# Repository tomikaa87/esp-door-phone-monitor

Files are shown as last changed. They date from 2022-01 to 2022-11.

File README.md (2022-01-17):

ESP Door Phone Monitor is an ESP8266-based device that monitors specific door phone types. It's able to check if the phone is ringing and also mute the ringer. The MQTT API makes it simple to integrate into various home automation systems, like Homebridge.

# Software

The ESP's firmware is based on Platform.io. It uses my own base library [esp-iot-base](https://github.com/tomikaa87/esp-iot-base) for fundamental functions like OTA updates, MQTT and Blynk integration, remote logging etc. In its current state the software is pretty simple and does only the basics for ringing detection and mute functions. In the future I plan to improve it with automatic unmuting when it detects that the receiver has been picked after ringing to ensure that the user hears the person on the other side of the line.

# Schematics

The schematics are made in KiCad. The circuit has an OP07 op-amp in differential mode which senses the ringing signal. The differential mode and the AC-coupling ensures that the monitor can sense the signal and be protected even if there is a difference in potential of the device's ground and the door phone's speaker signal. (In my case there is 90V potential difference between the speaker signal and the power supply's ground.)

The controller is an ESP12F module with all the necessary support circuits (power supply, nodemcu-style reset circuit for programming). The differential amplifier drives an input pin which measures the frequency of the signal in an interrupt and determines if there is a ringer signal.

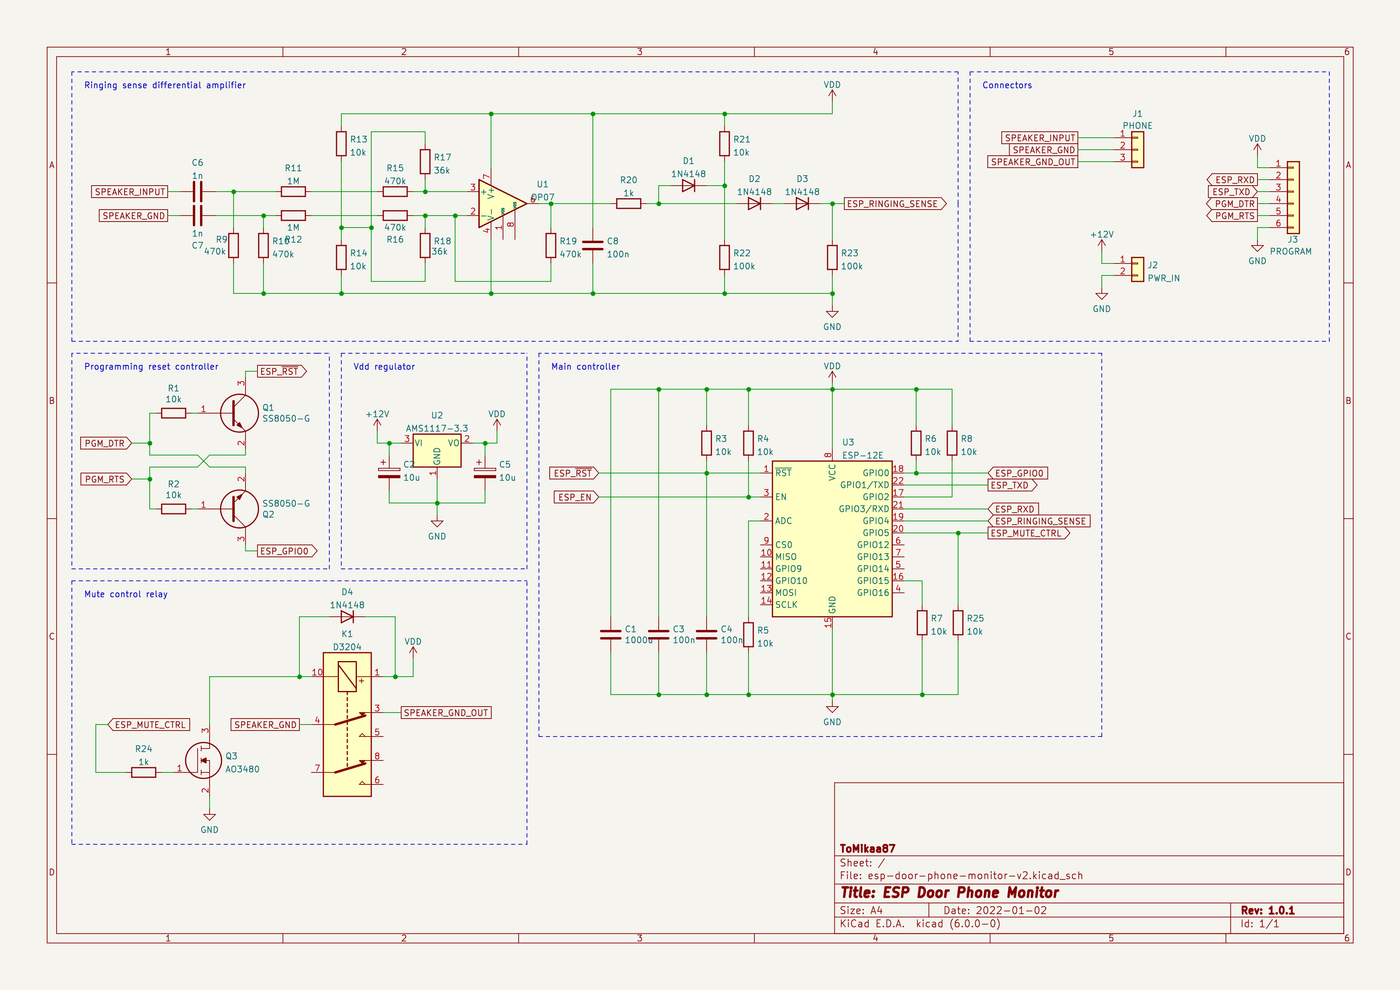
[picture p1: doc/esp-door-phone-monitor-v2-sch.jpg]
Schematics


# PCB degisn

The PCB design is made in KiCad as well and mostly uses SMD parts.

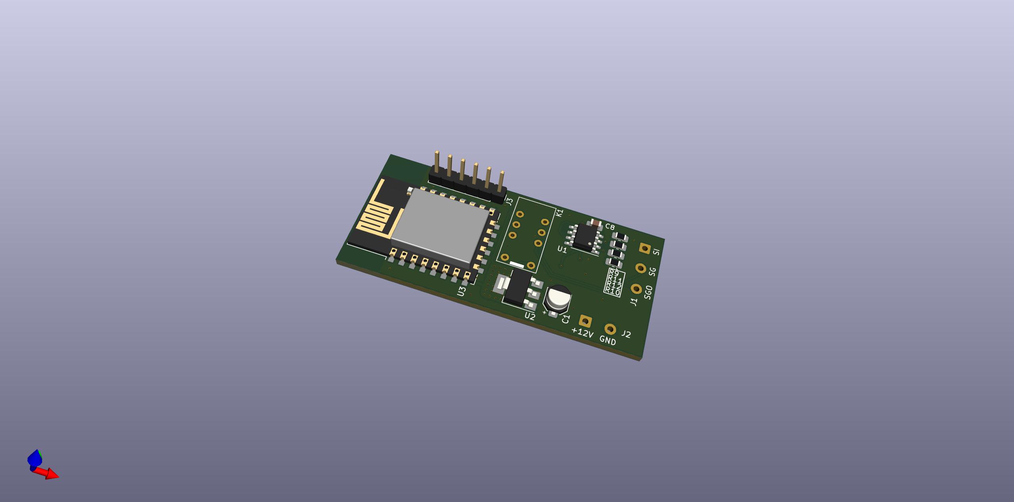
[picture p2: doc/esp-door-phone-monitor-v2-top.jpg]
PCB top

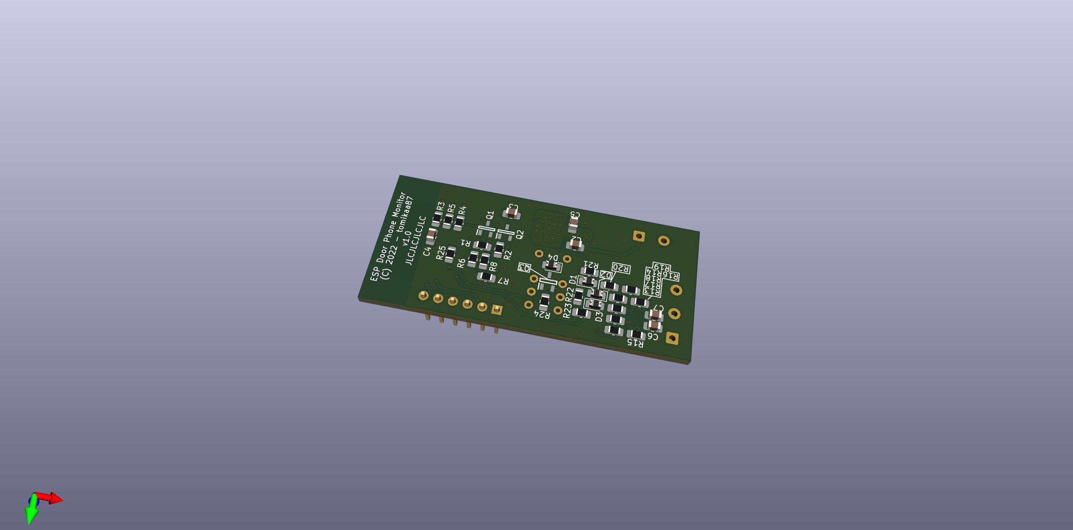
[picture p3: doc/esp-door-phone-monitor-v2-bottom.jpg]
PCB bottom


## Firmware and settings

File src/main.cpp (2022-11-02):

#include "DoorPhoneMonitor.h"
#include "PrivateConfig.h"

#include <Arduino.h>

#include <memory>

static std::unique_ptr<DoorPhoneMonitor> doorPhoneMonitor;

void setup()
{
    static ApplicationConfig appConfig;

    appConfig.firmwareVersion = VersionNumber{ 1, 2, 0 };

    appConfig.logging.syslog.enabled = true;
    appConfig.logging.syslog.hostName = Config::Logging::SyslogHostName;
    appConfig.logging.syslog.serverHostName = Config::Logging::SyslogServerHost;
    appConfig.logging.syslog.serverPort = Config::Logging::SyslogServerPort;

    appConfig.mqtt.brokerIp = Config::Mqtt::BrokerIp;
    appConfig.mqtt.brokerPort = Config::Mqtt::BrokerPort;
    appConfig.mqtt.enabled = true;
    appConfig.mqtt.id = Config::Mqtt::Id;
    appConfig.mqtt.user = Config::Mqtt::User;
    appConfig.mqtt.password = Config::Mqtt::Password;

    appConfig.persistence.Size = 8;

#ifdef IOT_ENABLE_HTTP_OTA_UPDATE
    appConfig.otaUpdate.updateCheckIntervalMs = 60000;
    appConfig.otaUpdate.updateUrl = Config::OtaUpdate::FirmwareUpdateUrl;
#endif
    appConfig.otaUpdate.arduinoOtaPasswordHash = Config::OtaUpdate::ArduinoOtaPasswordHash;

    appConfig.wifi.password = Config::WiFi::Password;
    appConfig.wifi.ssid = Config::WiFi::SSID;

    appConfig.hostName = Config::HostName;

    doorPhoneMonitor.reset(new DoorPhoneMonitor(appConfig));
}

void loop()
{
    doorPhoneMonitor->task();
}

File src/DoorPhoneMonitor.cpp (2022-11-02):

#include "DoorPhoneMonitor.h"
#include "Utils.h"

#include <cstdio>
#include <sstream>

namespace RingingSensor
{
    constexpr unsigned long CheckInvervalMs = 500;
    constexpr unsigned long ActiveStateTimeoutMs = 3000;
    constexpr auto CountThreshold = 100u;
}

namespace Pins
{
    constexpr auto Led = LED_BUILTIN;
    constexpr auto RingingSense = D2;
    constexpr auto RingerMute = D1;
}

DoorPhoneMonitor::DoorPhoneMonitor(const ApplicationConfig& appConfig)
    : _appConfig(appConfig)
    , _coreApplication(_appConfig)
    , _mqtt(_coreApplication.mqttClient())
{
    Logger::setup(_appConfig, _coreApplication.systemClock());

    setupMqtt();
    _coreApplication.setMqttUpdateHandler([this]{ updateMqtt(); });

    // Setup ringing sensor input pin
    pinMode(Pins::RingingSense, INPUT);
    attachInterruptArg(Pins::RingingSense, ringingSenseIsr, this, FALLING);

    // Setup speaker mute control pin, unmute by default
    pinMode(Pins::RingerMute, OUTPUT);
    setMute(Mute::Off);

    // LED pin for testing
    pinMode(Pins::Led, OUTPUT);
    setLed(Led::Off);
}

void DoorPhoneMonitor::task()
{
    _coreApplication.task();

    if (millis() - _ringingSensorCheckTime >= RingingSensor::CheckInvervalMs) {
        // Reset 'Sensor Check' timer
        _ringingSensorCheckTime = millis();

        if (_ringingSensorTriggerCount >= RingingSensor::CountThreshold) {
            _log.info_P(PSTR("ringing detected: triggerCount=%u"), _ringingSensorTriggerCount);

            // Reset 'Active State' timer
            _ringingStateCheckTime = millis();
            _mqtt.ringing = true;

            setLed(Led::On);
        }

        _ringingSensorTriggerCount = 0;
    }

    if (_mqtt.ringing && millis() - _ringingStateCheckTime >= RingingSensor::ActiveStateTimeoutMs) {
        _mqtt.ringing = false;

        setLed(Led::Off);

        _log.info_P(PSTR("ringing ended"));
    }
}

void DoorPhoneMonitor::setupMqtt()
{
    _mqtt.muted.setChangedHandler([this](const bool& muted) {
        _log.info_P(PSTR("mute state changed via MQTT: muted=%d"), muted ? 1 : 0);
        setMute(muted ? Mute::On : Mute::Off);
    });

    {
        std::stringstream config;

        config << '{';
        config << Utils::pgmToStdString(PSTR(R"("icon":"mdi:phone-ring")"));
        config << Utils::pgmToStdString(PSTR(R"(,"name":"Door Phone Ringing")"));
        config << Utils::pgmToStdString(PSTR(R"(,"object_id":"door_phone_monitor_ringing")"));
        config << Utils::pgmToStdString(PSTR(R"(,"unique_id":"door_phone_monitor_ringing")"));
        config << Utils::pgmToStdString(PSTR(R"(,"state_topic":"doorphone/ringing")"));
        config << '}';

        _coreApplication.mqttClient().publish(
            PSTR("homeassistant/sensor/door_phone_monitor_ringing/config"),
            config.str(),
            false
        );
    }

    {
        std::stringstream config;

        config << '{';
        config << Utils::pgmToStdString(PSTR(R"("icon":"mdi:volume-off")"));
        config << Utils::pgmToStdString(PSTR(R"(,"name":"Door Phone Mute")"));
        config << Utils::pgmToStdString(PSTR(R"(,"object_id":"door_phone_monitor_mute")"));
        config << Utils::pgmToStdString(PSTR(R"(,"unique_id":"door_phone_monitor_mute")"));
        config << Utils::pgmToStdString(PSTR(R"(,"command_topic":"doorphone/mute")"));
        config << Utils::pgmToStdString(PSTR(R"(,"state_topic":"doorphone/muted")"));
        config << Utils::pgmToStdString(PSTR(R"(,"payload_on":"1")"));
        config << Utils::pgmToStdString(PSTR(R"(,"payload_off":"0")"));
        config << Utils::pgmToStdString(PSTR(R"(,"state_on":"1")"));
        config << Utils::pgmToStdString(PSTR(R"(,"state_off":"0")"));
        config << '}';

        _coreApplication.mqttClient().publish(
            PSTR("homeassistant/switch/door_phone_monitor_mute/config"),
            config.str(),
            false
        );
    }

    updateMqtt();
}

void DoorPhoneMonitor::updateMqtt()
{
}

void DoorPhoneMonitor::setLed(const Led state)
{
    digitalWrite(Pins::Led, state == Led::On ? 0 : 1);
}

void DoorPhoneMonitor::setMute(const Mute state)
{
    digitalWrite(Pins::RingerMute, state == Mute::On ? 1 : 0);
}

void ICACHE_RAM_ATTR DoorPhoneMonitor::ringingSenseIsr(void* const arg)
{
    auto* self = static_cast<DoorPhoneMonitor*>(arg);
    ++self->_ringingSensorTriggerCount;
}

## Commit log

2021-12-23 Implement mute function
    [esp-door-phone-monitor.sch]
2022-01-02 Initial commit of schematics and PCB design
    [esp-door-phone-monitor-v2.kicad_pcb, esp-door-phone-monitor-v2.kicad_sch]
2022-01-02 Add LTspice schematics for differential amp simulations
2022-01-03 New, more compact PCB design
    [esp-door-phone-monitor-v2-B_Cu.gbr, esp-door-phone-monitor-v2-B_Mask.gbr, esp-door-phone-monitor-v2-B_Paste.gbr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]
2022-01-03 Even smaller PCB design
    [esp-door-phone-monitor-v2.kicad_pcb]
2022-01-03 Fix PCB issues
    [esp-door-phone-monitor-v2-B_Cu.gbr, esp-door-phone-monitor-v2-B_Mask.gbr, esp-door-phone-monitor-v2-B_Paste.gbr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]
2022-01-03 Prepare PCB for manufacturing
    [esp-door-phone-monitor-v2.kicad_pcb]
2022-01-03 Fix pull-down resistor on GPIO15
    [esp-door-phone-monitor-v2.kicad_pcb, esp-door-phone-monitor-v2.kicad_sch]
2022-01-17 Update the GPIO pin mapping according to the new PCB design
2022-01-17 Fix the reversed flyback diode D4
    [esp-door-phone-monitor-v2.kicad_pcb, esp-door-phone-monitor-v2.kicad_sch]
2022-01-29 Disable LED debug mode
2022-01-29 Read ArduinoOTA parameters from the environment
